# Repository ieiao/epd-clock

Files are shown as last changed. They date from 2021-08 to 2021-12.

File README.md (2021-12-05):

# EPD-CLOCK

## 简介

本项目使用了2.9寸电子价签中的墨水屏，出于个人爱好制作而成，目前仅设计了简单的基础功能，实物效果如下。

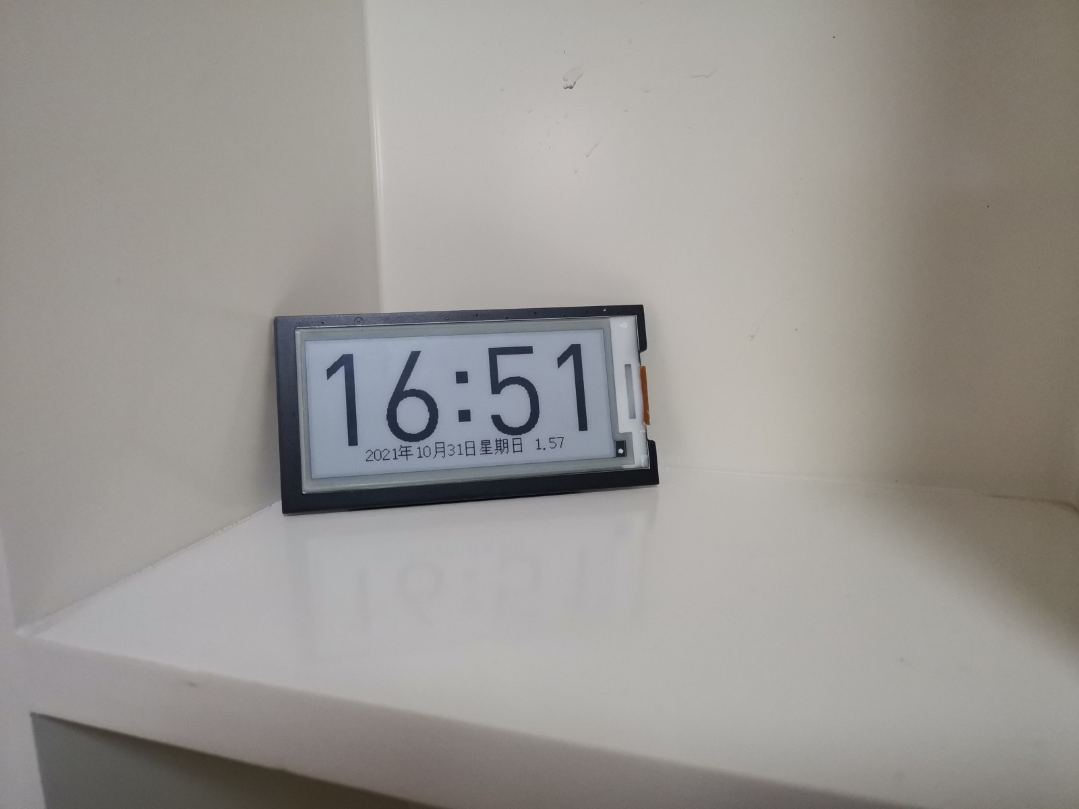
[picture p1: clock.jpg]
外观


经过估算，低功耗状态下的待机电流应该小于20uA，因测量设备不足无法测量故刷新功耗不详，单节电池可用寿命不详。经过简单测试，工作5周，每天工作时间16小时，电池电压从1.57V降至1.42V，仅供参考。

## 源码目录

```
├── fw                  # 固件
│   ├── binloader       #  SPI flash烧录固件，基于flashrom的serprog协议
│   └── clock           #  主固件
└── hw                  # 硬件，原理图、PCB及相关内容
```

## 硬件简介

本项目使用的墨水屏、MCU、SPI flash均来自电子价签，使用单节7号干电池升压供电，详细原理图及元器件信息见`hw`目录，本项目原理图等使用`KiCAD`进行绘制。

## 固件编译

项目中涉及到的两个固件程序均使用CMake进行管理，GCC作为编译器，在Debian 11发行版中进行构建。

## 字库烧录

本项目字库未采用全字库方案，而是只取了部分使用的字体，使用genmatrix([gitee](https://gitee.com/ieiao/genmatrix)|[github](https://github.com/ieiao/genmatrix))工具`xxd_format`分支进行了字符取模，使用`fw/binloader`程序来进行字库烧录。

`binloader`是[flashrom](https://flashrom.org/Flashrom)工具中serprog协议的一种实现，借助串口实现对spi flash内容的读写，虽然速度一般，但足以应对本项目使用的超小体积字库。

成功编译并且将binloader程序烧录到单片机后，使用任意USB转TTL串口连接设备与电脑，此时便可以借助flashrom对SPI flash进行烧录了，烧录文件见`fw/clock/flash/font.bin`。

> 如果不介意烧录速度慢的话可以将字库文件pad一段数据到flash容量大小后进行全片烧录；如果介意烧录速度的话可以使用flashrom的layout特性仅烧录指定的部分，或者使用其他高速烧录器烧录后再进行焊接。

## 主程序说明

主程序目前只实现了时间日期显示及调节、电池电压监测以及简易的夜间模式，基本满足看时间的需求。

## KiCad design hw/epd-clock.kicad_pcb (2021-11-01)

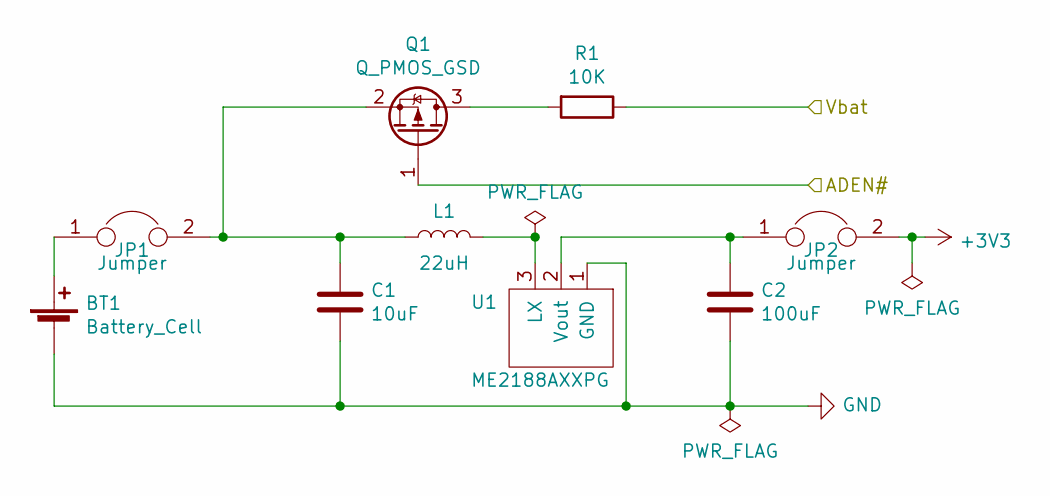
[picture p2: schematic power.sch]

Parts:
BT1: Battery_Cell; AAA_holder_smt
C1: 10uF; C_0603_1608Metric
C2: 100uF; C_1206_3216Metric
JP1, JP2: Jumper; SolderJumper-2_P1.3mm_Open_RoundedPad1.0x1.5mm
L1: 22uH; L_Coilcraft_XxL4020
Q1: Q_PMOS_GSD; SOT-23
R1: 10K; R_0603_1608Metric
U1: ME2188AXXPG; SOT-89-3

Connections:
+3V3: JP2.2; also elsewhere on the board
/mcu/AIN: R1.1; also elsewhere on the board
/power/ADEN#: Q1.1 (G); also elsewhere on the board
GND: BT1.2 (-), C1.2, C2.2, U1.1 (GND); also elsewhere on the board
unnamed: BT1.1 (+), JP1.1
unnamed: C1.1, JP1.2, L1.1, Q1.2 (S)
unnamed: C2.1, JP2.1, U1.2 (Vout)
unnamed: L1.2, U1.3 (LX)
unnamed: Q1.3 (D), R1.2

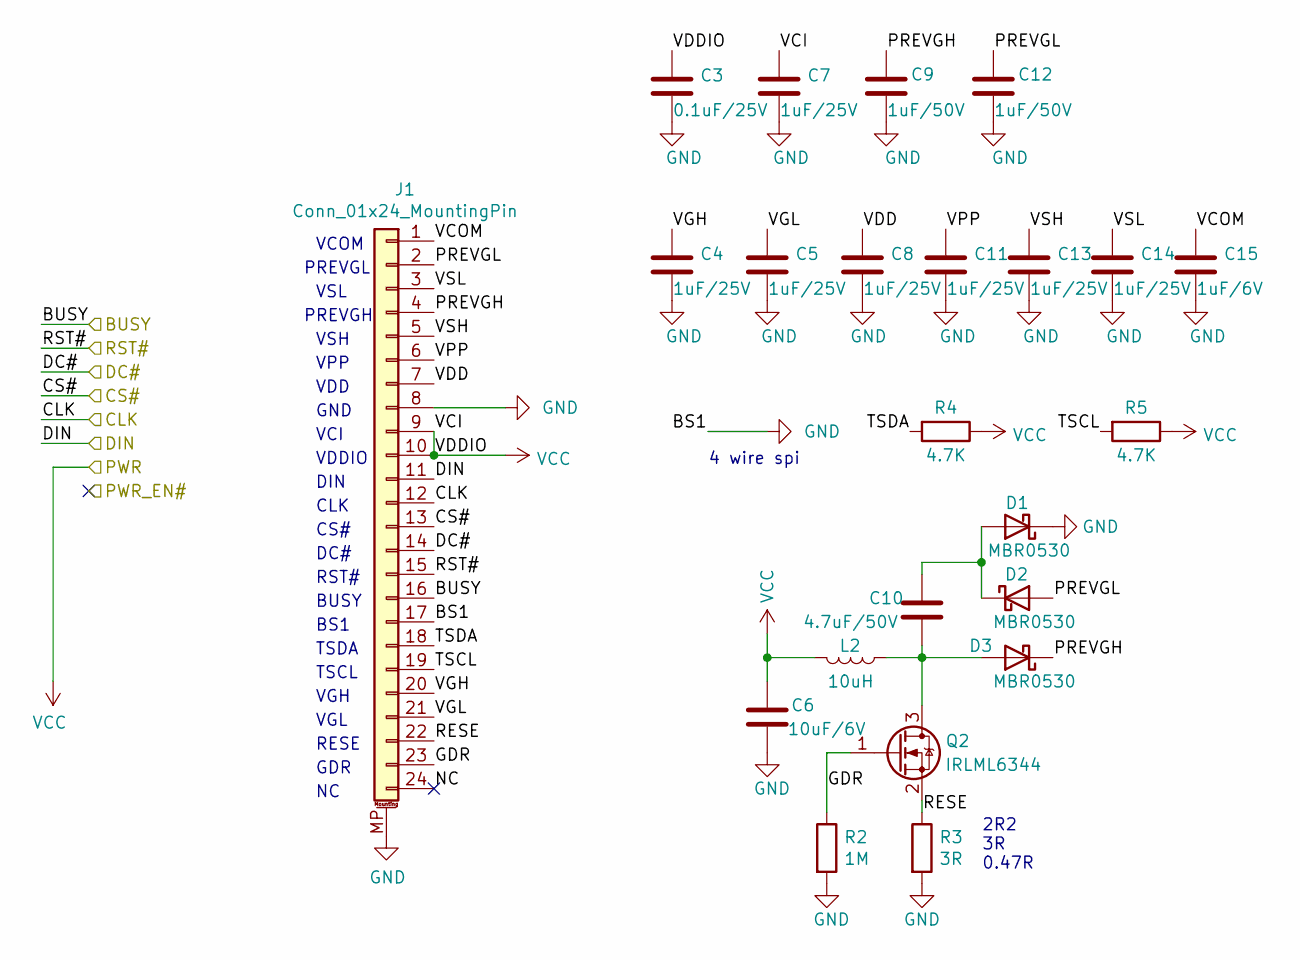
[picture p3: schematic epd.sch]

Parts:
C3: 0.1uF/25V; C_0603_1608Metric
C4, C5, C7, C8, C11, C13, C14: 1uF/25V; C_0603_1608Metric
C6: 10uF/6V; C_0603_1608Metric
C9, C12: 1uF/50V; C_0603_1608Metric
C10: 4.7uF/50V; C_0805_2012Metric
C15: 1uF/6V; C_0603_1608Metric
D1, D2, D3: MBR0530; D_SOD-123
J1: Conn_01x24_MountingPin; TE_2-1734839-4_1x24-1MP_P0.5mm_Horizontal
L2: 10uH; L_Coilcraft_XxL4020
Q2: IRLML6344; SOT-23
R2: 1M; R_0603_1608Metric
R3: 3R; R_0603_1608Metric
R4, R5: 4.7K; R_0603_1608Metric

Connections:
+3V3: C3.1, C6.2, C7.1, J1.9, J1.10, L2.2, R4.1, R5.1; also elsewhere on the board
/epd/BUSY: J1.16; also elsewhere on the board
/epd/CLK: J1.12; also elsewhere on the board
/epd/CS#: J1.13; also elsewhere on the board
/epd/DC#: J1.14; also elsewhere on the board
/epd/DIN: J1.11; also elsewhere on the board
/epd/GDR: J1.23, Q2.1 (G), R2.1
/epd/NC: J1.24
/epd/PREVGH: C9.1, D3.1 (K), J1.4
/epd/PREVGL: C12.1, D2.2 (A), J1.2
/epd/RESE: J1.22, Q2.2 (S), R3.1
/epd/TSCL: J1.19, R5.2
/epd/TSDA: J1.18, R4.2
/epd/VCOM: C15.1, J1.1
/epd/VDD: C8.1, J1.7
/epd/VGH: C4.1, J1.20
/epd/VGL: C5.1, J1.21
/epd/VPP: C11.1, J1.6
/epd/VSH: C13.1, J1.5
/epd/VSL: C14.1, J1.3
/mcu/EPD_RST#: J1.15; also elsewhere on the board
GND: C3.2, C4.2, C5.2, C6.1, C7.2, C8.2, C9.2, C11.2, C12.2, C13.2, C14.2, C15.2, D1.1 (K), J1.8, J1.17, J1.MP (MountPin), R2.2, R3.2; also elsewhere on the board
unnamed: C10.1, D3.2 (A), L2.1, Q2.3 (D)
unnamed: C10.2, D1.2 (A), D2.1 (K)

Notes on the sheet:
4 wire spi
GDR
RESE
VGL
VGH
TSCL
TSDA
BS1
BUSY
RST#
DC#
CS#
CLK
DIN
VDDIO
VCI
GND
VDD
VPP
VSH
PREVGH
VSL
PREVGL
VCOM
2R2 3R 0.47R

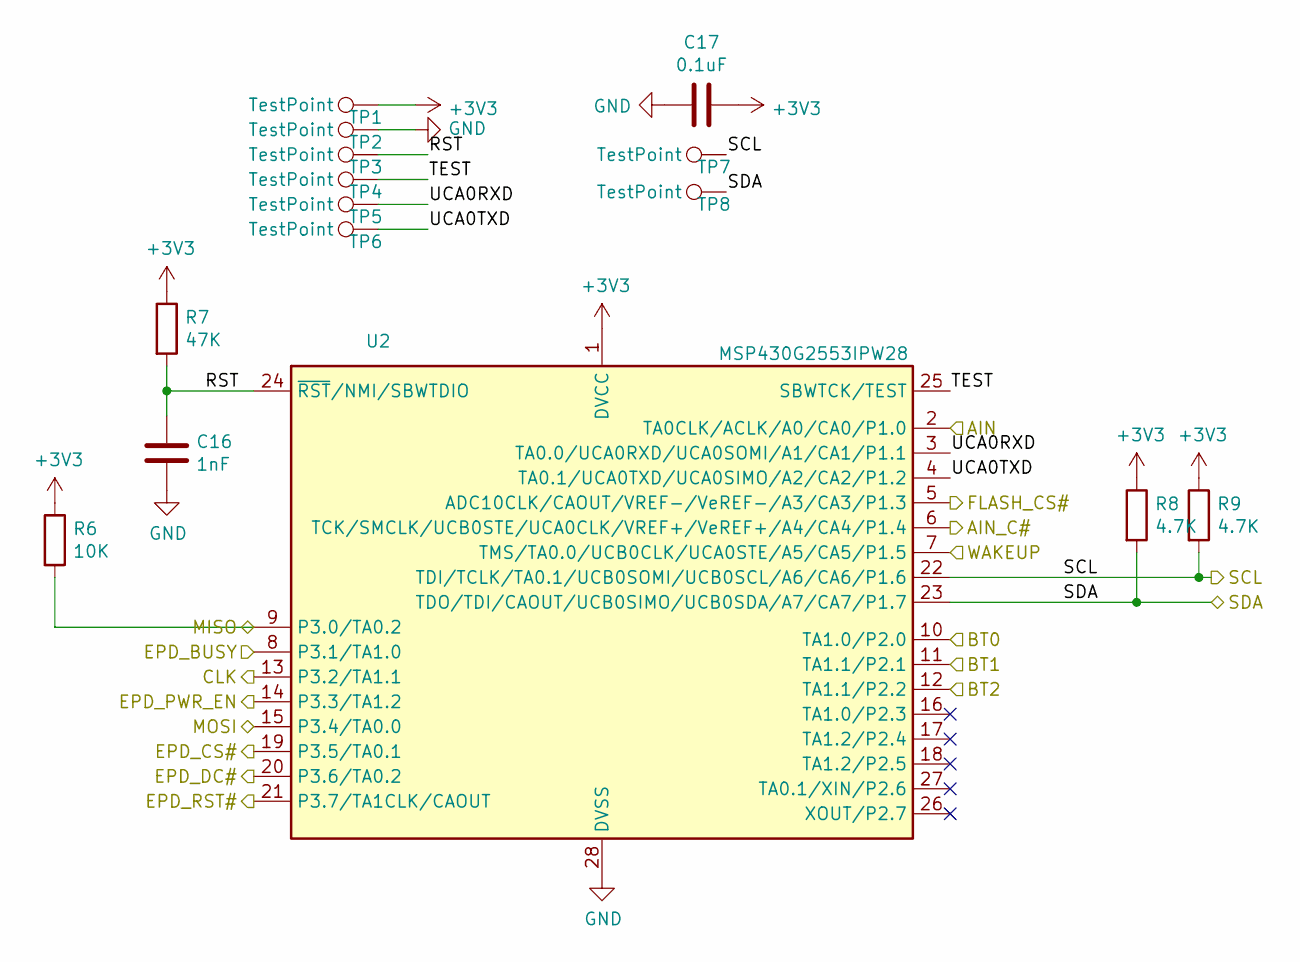
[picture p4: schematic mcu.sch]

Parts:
C16: 1nF; C_0603_1608Metric
C17: 0.1uF; C_0603_1608Metric
R6: 10K; R_0603_1608Metric
R7: 47K; R_0603_1608Metric
R8, R9: 4.7K; R_0603_1608Metric
TP1, TP2, TP3, TP4, TP5, TP6, TP7, TP8: TestPoint; TestPoint_Pad_D1.0mm
U2: MSP430G2553IPW28; TSSOP-28_4.4x9.7mm_P0.65mm

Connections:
+3V3: C17.1, R6.1, R7.1, R8.1, R9.1, TP1.1, U2.1 (DVCC); also elsewhere on the board
/button/BT0: U2.10 (TA1.0/P2.0); also elsewhere on the board
/button/BT1: U2.11 (TA1.1/P2.1); also elsewhere on the board
/button/BT2: U2.12 (TA1.1/P2.2); also elsewhere on the board
/epd/BUSY: U2.8 (P3.1/TA1.0); also elsewhere on the board
/epd/CLK: U2.13 (P3.2/TA1.1); also elsewhere on the board
/epd/CS#: U2.19 (P3.5/TA0.1); also elsewhere on the board
/epd/DC#: U2.20 (P3.6/TA0.2); also elsewhere on the board
/epd/DIN: U2.15 (P3.4/TA0.0); also elsewhere on the board
/flash/CS: U2.5 (ADC10CLK/CAOUT/VREF-/VeREF-/A3/CA3/P1.3); also elsewhere on the board
/flash/MISO: R6.2, U2.9 (P3.0/TA0.2); also elsewhere on the board
/mcu/AIN: U2.2 (TA0CLK/ACLK/A0/CA0/P1.0); also elsewhere on the board
/mcu/EPD_PWR_EN: U2.14 (P3.3/TA1.2)
/mcu/EPD_RST#: U2.21 (P3.7/TA1CLK/CAOUT); also elsewhere on the board
/mcu/RST: C16.1, R7.2, TP3.1, U2.24 (~RST~/NMI/SBWTDIO)
/mcu/SCL: R9.2, TP7.1, U2.22 (TDI/TCLK/TA0.1/UCB0SOMI/UCB0SCL/A6/CA6/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); also elsewhere on the board
/mcu/SDA: R8.2, TP8.1, U2.23 (TDO/TDI/CAOUT/UCB0SIMO/UCB0SDA/A7/CA7/P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); also elsewhere on the board
/mcu/TEST: TP4.1, U2.25 (SBWTCK/TEST)
/mcu/UCA0RXD: TP5.1, U2.3 (TA0.0/UCA0RXD/UCA0SOMI/A1/CA1/P1.1)
/mcu/UCA0TXD: TP6.1, U2.4 (TA0.1/UCA0TXD/UCA0SIMO/A2/CA2/P1.2)
/power/ADEN#: U2.6 (TCK/SMCLK/UCB0STE/UCA0CLK/VREF+/VeREF+/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); also elsewhere on the board
/rtc/INT: U2.7 (TMS/TA0.0/UCB0CLK/UCA0STE/A5/CA5/P1.5); also elsewhere on the board
GND: C16.2, C17.2, TP2.1, U2.28 (DVSS); also elsewhere on the board

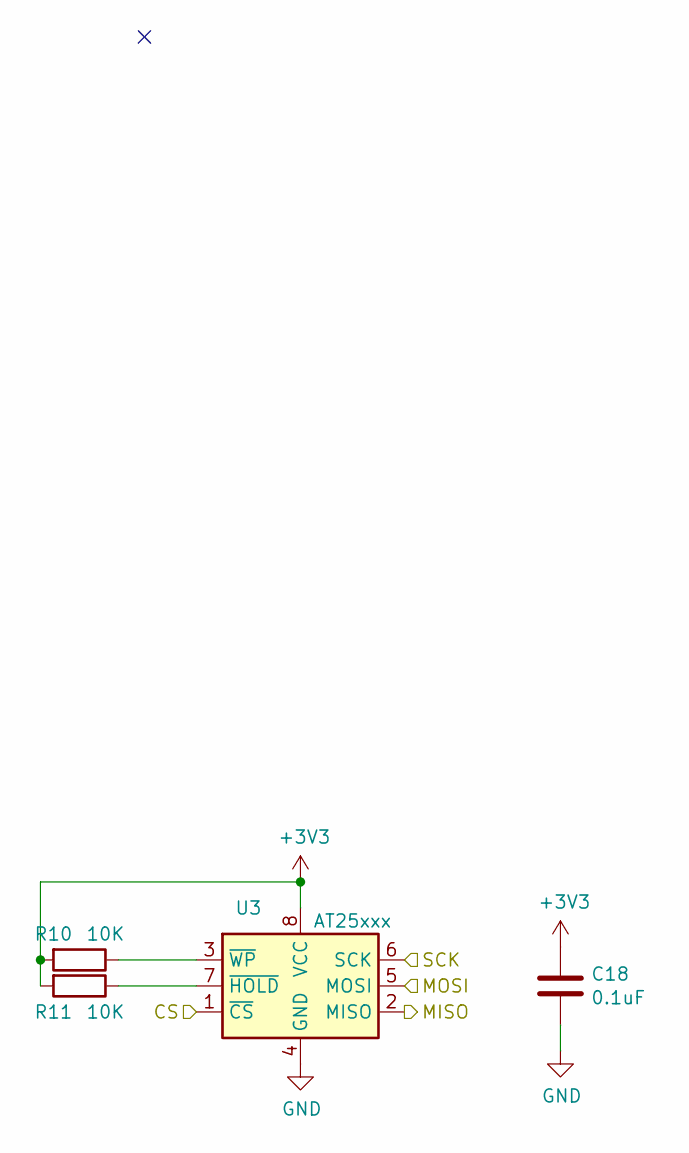
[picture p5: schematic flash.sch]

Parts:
C18: 0.1uF; C_0603_1608Metric
R10, R11: 10K; R_0603_1608Metric
U3: AT25xxx; SOIC-8_5.275x5.275mm_P1.27mm

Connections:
+3V3: C18.1, R10.2, R11.2, U3.8 (VCC); also elsewhere on the board
/epd/CLK: U3.6 (SCK); also elsewhere on the board
/epd/DIN: U3.5 (MOSI); also elsewhere on the board
/flash/CS: U3.1 (~CS); also elsewhere on the board
/flash/MISO: U3.2 (MISO); also elsewhere on the board
GND: C18.2, U3.4 (GND); also elsewhere on the board
unnamed: R10.1, U3.3 (~WP)
unnamed: R11.1, U3.7 (~HOLD)

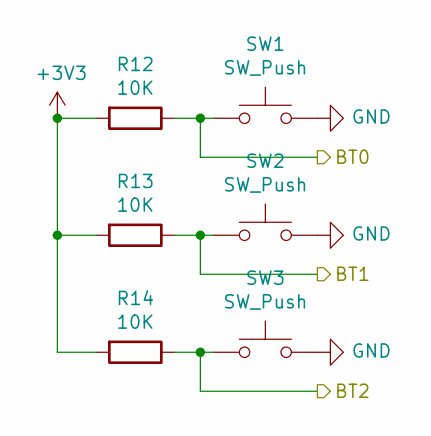
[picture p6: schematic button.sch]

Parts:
R12, R13, R14: 10K; R_0603_1608Metric
SW1, SW2, SW3: SW_Push; SW_Push_1P1T_NO_6x6mm_H9.5mm

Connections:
+3V3: R12.2, R13.2, R14.2; also elsewhere on the board
/button/BT0: R12.1, SW1.1; also elsewhere on the board
/button/BT1: R13.1, SW2.1; also elsewhere on the board
/button/BT2: R14.1, SW3.1; also elsewhere on the board
GND: SW1.2, SW2.2, SW3.2; also elsewhere on the board

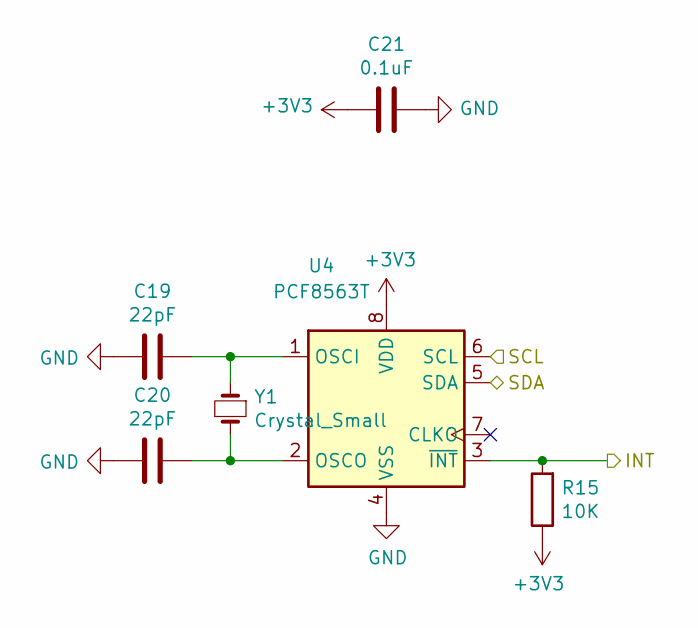
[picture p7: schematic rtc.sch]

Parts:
C19, C20: 22pF; C_0603_1608Metric
C21: 0.1uF; C_0603_1608Metric
R15: 10K; R_0603_1608Metric
U4: PCF8563T; SOIC-8_3.9x4.9mm_P1.27mm
Y1: Crystal_Small; Crystal_DS26_D2.0mm_L6.0mm_Horizontal_1EP_style1

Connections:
+3V3: C21.2, R15.1, U4.8 (VDD); also elsewhere on the board
/mcu/SCL: U4.6 (SCL); also elsewhere on the board
/mcu/SDA: U4.5 (SDA); also elsewhere on the board
/rtc/INT: R15.2, U4.3 (~INT~); also elsewhere on the board
GND: C19.2, C20.2, C21.1, U4.4 (VSS); also elsewhere on the board
unnamed: C19.1, U4.1 (OSCI), Y1.1
unnamed: C20.1, U4.2 (OSCO), Y1.2

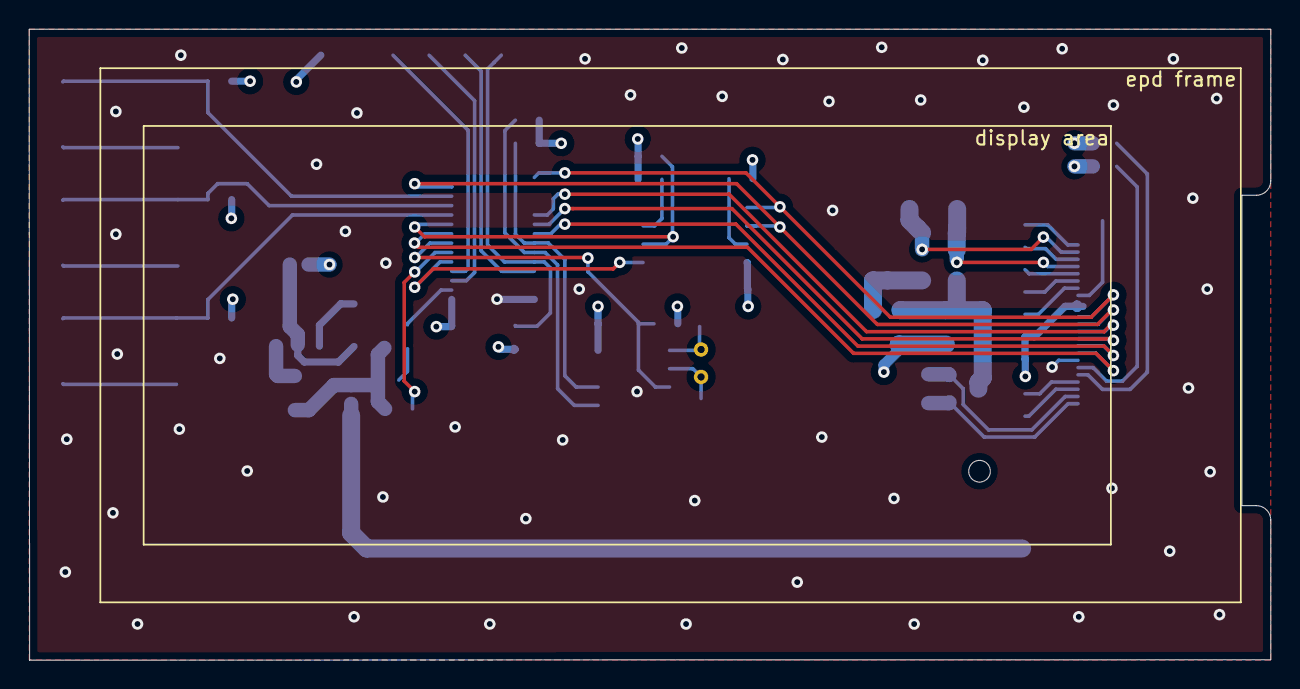
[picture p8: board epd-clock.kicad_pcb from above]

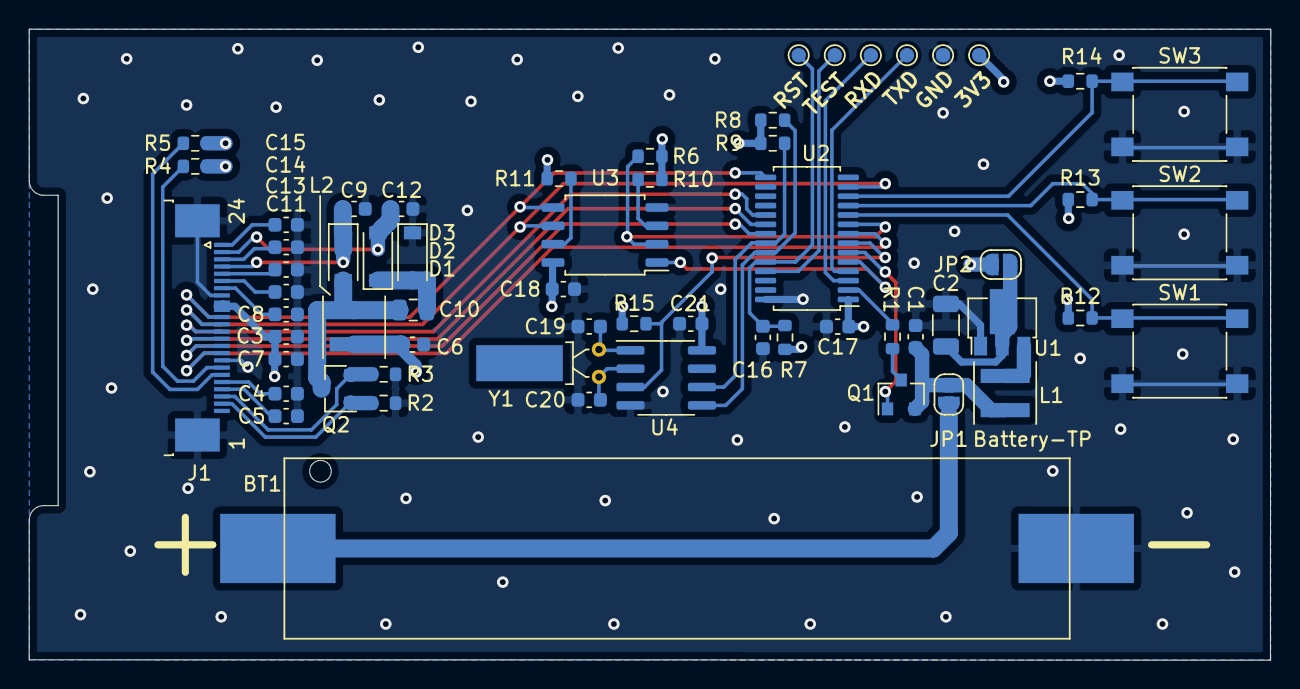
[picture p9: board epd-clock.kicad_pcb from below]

Board: 4 copper layers, 86.0 x 43.7 mm, 61 parts (61 on the bottom side), 46 nets.

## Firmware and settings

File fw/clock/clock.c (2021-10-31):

#include <msp430g2553.h>
#include <stdio.h>
#include <stdint.h>
#include <stdbool.h>
#include "drivers/platform.h"
#include "drivers/pm.h"
#include "drivers/uart.h"
#include "drivers/gpio.h"
#include "drivers/spi.h"
#include "drivers/i2c.h"
#include "drivers/epd-2in9.h"
#include "drivers/timer.h"
#include "lib/time.h"
#include "lib/pcf8563.h"
#include "lib/spi-nor.h"
#include "sys/core.h"

int main()
{
    platform_init();
    gpio_init();
    i2c_init();
    int_enable();
    timer_init();
    
    main_loop();

    while(1);
    return 0;
}

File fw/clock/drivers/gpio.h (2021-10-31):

#ifndef _GPIO_H_
#define _GPIO_H_

#include <msp430g2553.h>

#define EPD_PWR_CTL_PIN    BIT3
#define EPD_PWR_CTL_PORT   P3OUT
#define EPD_PWR_ON         (EPD_PWR_CTL_PORT &= ~EPD_PWR_CTL_PIN)
#define EPD_PWR_OFF        (EPD_PWR_CTL_PORT |= EPD_PWR_CTL_PIN)

#define EPD_BUSY_PIN       BIT1
#define EPD_BUSY_PORT      P3IN
#define EPD_BUSY_STATE     (EPD_BUSY_PORT & EPD_BUSY_PIN)

#define EPD_DC_PIN         BIT6
#define EPD_DC_PORT        P3OUT
#define EPD_DC_SET         (EPD_DC_PORT |= EPD_DC_PIN)
#define EPD_DC_RESET       (EPD_DC_PORT &= ~EPD_DC_PIN)

#define EPD_RESET_PIN      BIT7
#define EPD_RESET_PORT     P3OUT
#define EPD_RESET_SET      (EPD_RESET_PORT |= EPD_RESET_PIN)
#define EPD_RESET_RESET    (EPD_RESET_PORT &= ~EPD_RESET_PIN)

#define EPD_CS_PIN         BIT5
#define EPD_CS_PORT        P3OUT
#define EPD_CS_SET         (EPD_CS_PORT |= EPD_CS_PIN)
#define EPD_CS_RESET       (EPD_CS_PORT &= ~EPD_CS_PIN)

#define SPI_NOR_CS_PIN     BIT3
#define SPI_NOR_CS_PORT    P1OUT
#define SPI_NOR_CS_SET     (SPI_NOR_CS_PORT |= SPI_NOR_CS_PIN)
#define SPI_NOR_CS_RESET   (SPI_NOR_CS_PORT &= ~SPI_NOR_CS_PIN)

#define ADC_CTL_PIN        BIT4
#define ADC_CTL_PORT       P1OUT
#define ADC_LINK_ON        (ADC_CTL_PORT &= ~ADC_CTL_PIN)
#define ADC_LINK_OFF       (ADC_CTL_PORT = ADC_CTL_PIN)

#define BT0_PIN            BIT0
#define BT0_PORT           P2IN
#define BT0_STATE          (BT0_PORT & BT0_PIN)
#define BT0_PUSHED         (BT0_STATE == 0)

#define BT1_PIN            BIT1
#define BT1_PORT           P2IN
#define BT1_STATE          (BT1_PORT & BT1_PIN)
#define BT1_PUSHED         (BT1_STATE == 0)

#define BT2_PIN            BIT2
#define BT2_PORT           P2IN
#define BT2_STATE          (BT2_PORT & BT2_PIN)
#define BT2_PUSHED         (BT2_STATE == 0)

#define ENABLE_BUTTON_WAKEUP    (P2IE |= (BIT0 + BIT1 + BIT2))

void gpio_init(void);
void gpio_resume(void);

#endif

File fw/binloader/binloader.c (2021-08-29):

#include <msp430g2553.h>
#include <stdio.h>
#include <stdlib.h>
#include "serprog.h"
#include "drivers/uart.h"
#include "drivers/gpio.h"
#include "drivers/spi.h"

#define PGMNAME "msp-serprog"
#define CMD_MAP (\
    (1L << S_CMD_NOP)        | \
    (1L << S_CMD_Q_IFACE)    | \
    (1L << S_CMD_Q_CMDMAP)   | \
    (1L << S_CMD_Q_PGMNAME)  | \
    (1L << S_CMD_Q_SERBUF)   | \
    (1L << S_CMD_Q_BUSTYPE)  | \
    (1L << S_CMD_SYNCNOP)    | \
    (1L << S_CMD_S_BUSTYPE)  | \
    (1L << S_CMD_O_SPIOP)      \
)
#define BUS_SPI (1 << 3)

void handle_command(int8_t c)
{
    u_int32_t i = 0;
    u_int32_t slen;
    u_int32_t rlen;

    switch(c) {
    case S_CMD_NOP:
        uart_putc(S_ACK);
        break;

    case S_CMD_Q_IFACE:
        uart_putc(S_ACK);
        uart_putc(0x1);
        uart_putc(0x0);
        break;

    case S_CMD_Q_CMDMAP:
        uart_putc(S_ACK);
        uart_putc(CMD_MAP & 0xff);
        uart_putc((CMD_MAP >> 8) & 0xff);
        uart_putc((CMD_MAP >> 16) & 0xff);
        uart_putc((CMD_MAP >> 24) & 0xff);
        for (i = 0; i < (32-4); i++)
            uart_putc(0x0);
        break;
    
    case S_CMD_Q_PGMNAME:
        uart_putc(S_ACK);
        while (PGMNAME[i])
        {
            uart_putc(PGMNAME[i]);
            i++;
        }
        for (; i < 16; i++)
            uart_putc(0x00);
        break;
    
    case S_CMD_Q_SERBUF:
        uart_putc(S_ACK);
        uart_putc(0xff);
        uart_putc(0xff);
        break;
    
    case S_CMD_Q_BUSTYPE:
        uart_putc(S_ACK);
        uart_putc(BUS_SPI);
        break;

    case S_CMD_SYNCNOP:
        uart_putc(S_NAK);
        uart_putc(S_ACK);
        break;

    case S_CMD_S_BUSTYPE:
        if ( (uart_getc()|BUS_SPI) == BUS_SPI)
            uart_putc(S_ACK);
        else
            uart_putc(S_NAK);
        break;

    case S_CMD_O_SPIOP:
        uart_putc(S_ACK);
        slen = uart_getc() | (uart_getc() << 8) | (((u_int32_t)uart_getc()) << 16);
        rlen = uart_getc() | (uart_getc() << 8) | (((u_int32_t)uart_getc()) << 16);

        P1OUT &= ~BIT3;
        if (slen) {
            for (i = 0; i < slen; i++)
                __spi_rw_byte(uart_getc());
        }
        if (rlen) {
            for (i = 0; i < rlen; i++)
                uart_putc(__spi_rw_byte(0xff));
        }
        P1OUT |= BIT3;
        break;

    default:
        uart_putc(S_NAK);
        break;
    }
}

void main()
{
    volatile char i;

    WDTCTL = WDTPW + WDTHOLD; // Stop WDT
    if (CALBC1_16MHZ == 0xFF)  // If calibration constant erased
    {
        while (1)
            ; // do not load, trap CPU!!
    }
    DCOCTL = 0;             // Select lowest DCOx and MODx settings
    BCSCTL1 = CALBC1_16MHZ; // Set DCO
    DCOCTL = CALDCO_16MHZ;

    gpio_init();
    uart_init();

    while (1)
        handle_command(uart_getc());
}

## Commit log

2021-08-14 epd-clock: v0.1
    [button.sch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]
2021-08-14 epd-clock: hw v0.2
    [button.sch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]
2021-08-14 epd-clock hw: add i2c test point
    [epd-clock.kicad_pcb, mcu.sch]
2021-08-15 epd-clock: hw add wakeup pin pull up register
    [epd-clock-B_Cu.gbr, epd-clock-B_Mask.gbr, epd-clock-B_SilkS.gbr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]
2021-08-15 epd-clock: hw change C8 footprint
    [epd-clock-B_Cu.gbr, epd-clock-B_Mask.gbr, epd-clock-B_SilkS.gbr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]
2021-08-18 epd-clock: hw: v0.2
    [button.sch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]
2021-08-29 epd-clock: 初步增加一些代码
2021-09-05 epd-clock: binloader修改适配v0.2版本的原理图
2021-09-09 epd-clock: 屏幕绘制,字符串处理,字库检索初步进行了验证
2021-09-12 epd-clock: 低功耗逻辑进行了初步验证，增加了按键检测的实现
2021-09-23 hw: 修正几个元件的参数
    [epd.sch]
2021-10-31 fw clock: 添加基础校时功能
2021-10-31 fw: clock: 完善功能
2021-11-01 hw: 合并电源网络
    取消墨水屏电源控制mos与独立电源域，墨水屏使用深度休眠模式，共用主
    电源域。
    [button.sch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]
2021-11-19 增加README说明文档
2021-11-27 更新ibom
2021-11-27 更新电池使用情况
2021-12-05 fw: clock: 优化按键长按的检测逻辑
2021-12-05 fw: clock: 调整电量检测计算方法，减小程序文件体积
